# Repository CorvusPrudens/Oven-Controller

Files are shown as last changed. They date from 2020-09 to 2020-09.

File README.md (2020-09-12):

# Oven-Controller
 Hardware, firmware, and support software for an ATMEGA 328-P based reflow oven controller.

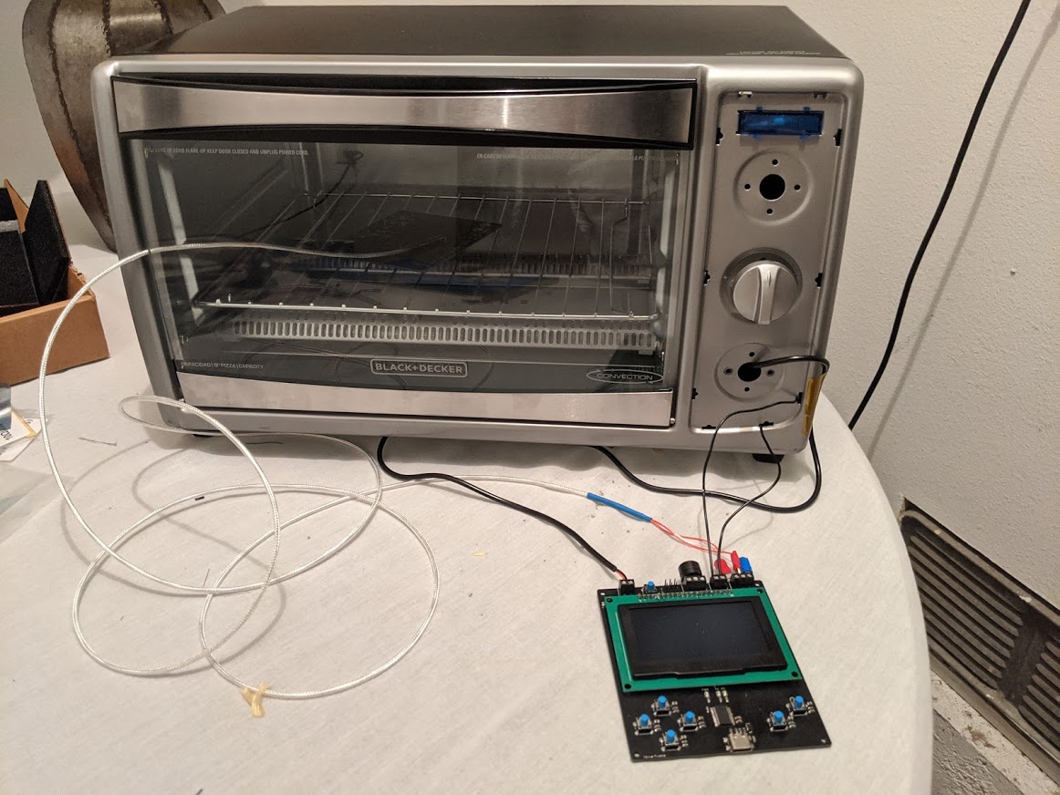
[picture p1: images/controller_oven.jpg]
Oven Controller


## Hardware
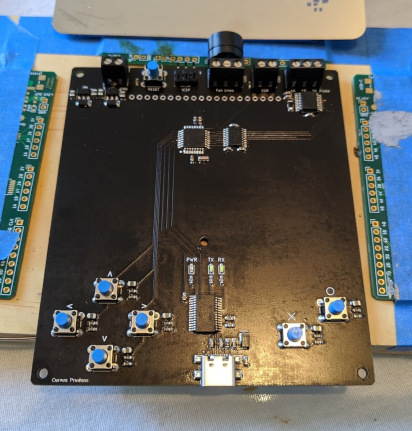
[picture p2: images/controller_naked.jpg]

 The board is controlled by an ATMEGA328-P microcontroller running at 20 MHz. USB communication and flashing is handled with an FT232R USB to UART IC. The board uses a USB-C connector because every modern device should.

 The controller includes a MAX31865 PTD temperature sensor IC with headers for a three-wire PTD probe, a solid state relay, and two additional gpio. The board also include a 7-12 volt power input header and a standard Arduino ICSP header for bootloader flashing.

 The most prominent feature is, of course, the 128x64 pixel OLED display. The on-screen UI is navigated with the 6 pushbuttons arranged in a gamepad-like fashion.

 The board was designed in kiCad, but can be easily ported to Eagle.
<br /><br />
## Firmware
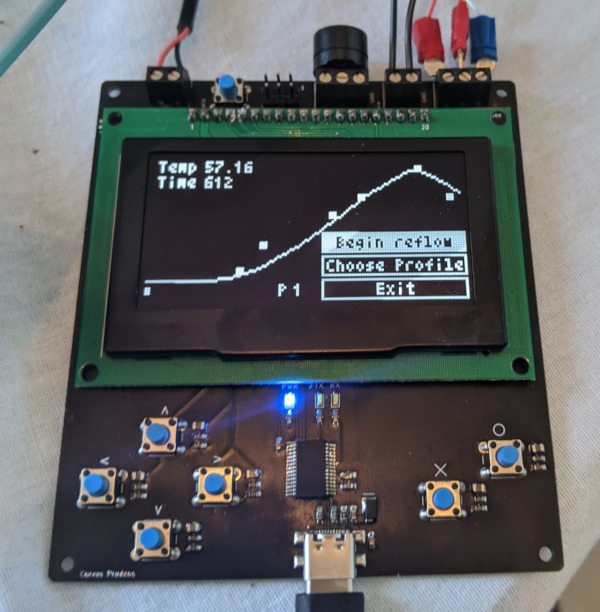
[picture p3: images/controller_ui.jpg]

 The firmware provides an intuitive, menu-based UI for the user. Without any programming or reflashing, the user can define up to eight temperature profiles that persist even after power cycling. These profiles can then be called up to control a modified toaster oven via a solid state relay.

 The firmware provides out of the box support for a piezo buzzer on the available gpio terminal, which provides feedback for UI navigation and an open-door notification.
<br /><br /><br /><br /><br /><br /><br /><br /><br /><br />
## Software
 I have also written a few support programs with Processing and Python. They perform various functions, including generating timer settings for different clock frequencies, generating playable note sequences given a semi-intuitive note table entry, generating bitmaps from images (ideally monochromatic or dichromatic images), and a program that allows a connected computer to log and display the live temperature profile as recorded by the controller.

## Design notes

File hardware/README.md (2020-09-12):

# Hardware

<!-- ![kiCad Design](../images/controller_design.png) -->
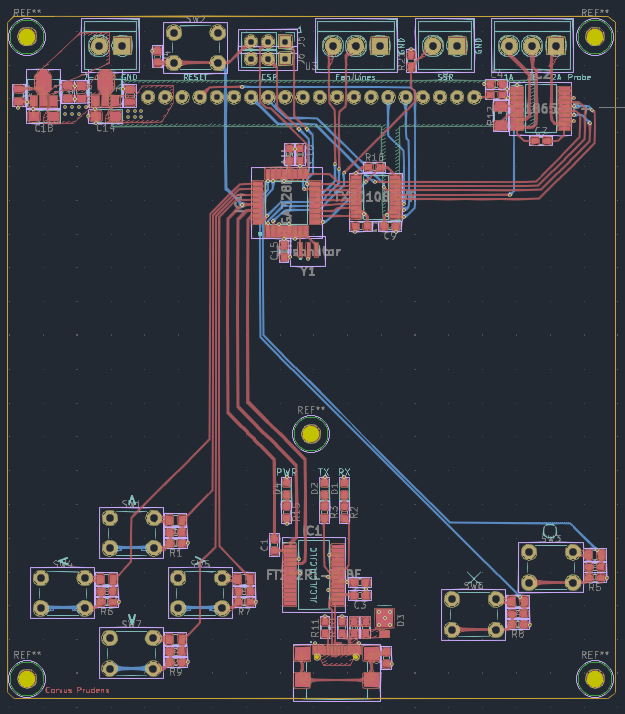
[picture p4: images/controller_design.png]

 This board combines several convenient features together to make an easy to use and highly capable reflow (toaster) oven controller. At the heart of the design is an ATMEGA328-P, with a few support features similar to what you might find on an Arduino board. This allows easy integration with the large Arduino ecosystem and convenient communication and flashing via USB (after flashing a bootloader via the ICSP header). To maximize performance, the 328-P is run at 5 volts -- supplied by either the USB Vbus or the included 7-12 volts LDO regulator. This allows the microcontroller to run at its highest rated frequency, 20 MHz, which is just enough to run all the UI screens at 30 frames per second.

 While the microcontroller can accept 5 volts, the two SPI connected modules -- the MAX31865 PTD probe sensor IC and the OLED display -- need 3.3 volts. Their power is supplied through another LDO, and the communication is routed through a very convenient level shifter, the TXB0108.

 The board itself is a 4 layer design. Of course, 4 layers is completely overkill for this design and would make no sense for a high-volume product. However, this is _not_ a high-volume product, and the manufacturer I use just so happened to drop their 4 layer prices insanely low. I'd be crazy not to make it 4!

 Finally, I'd like to highlight the use of USB-C. If I ever include USB functionality on a device, I will _always_ choose USB-C if I am able. Not only is it an aesthetically pleasing, reversible, fast, and powerful connection -- it's _dead easy_ to design with assuming you don't need its fancier features like power delivery or USB 3.0 (or the dreadfully named USB 3.1 gen 2!). All that's needed for a basic implementation is two resistors and a convenient USB 2.0 rated connector like the one I've used on this board. Give it a try!

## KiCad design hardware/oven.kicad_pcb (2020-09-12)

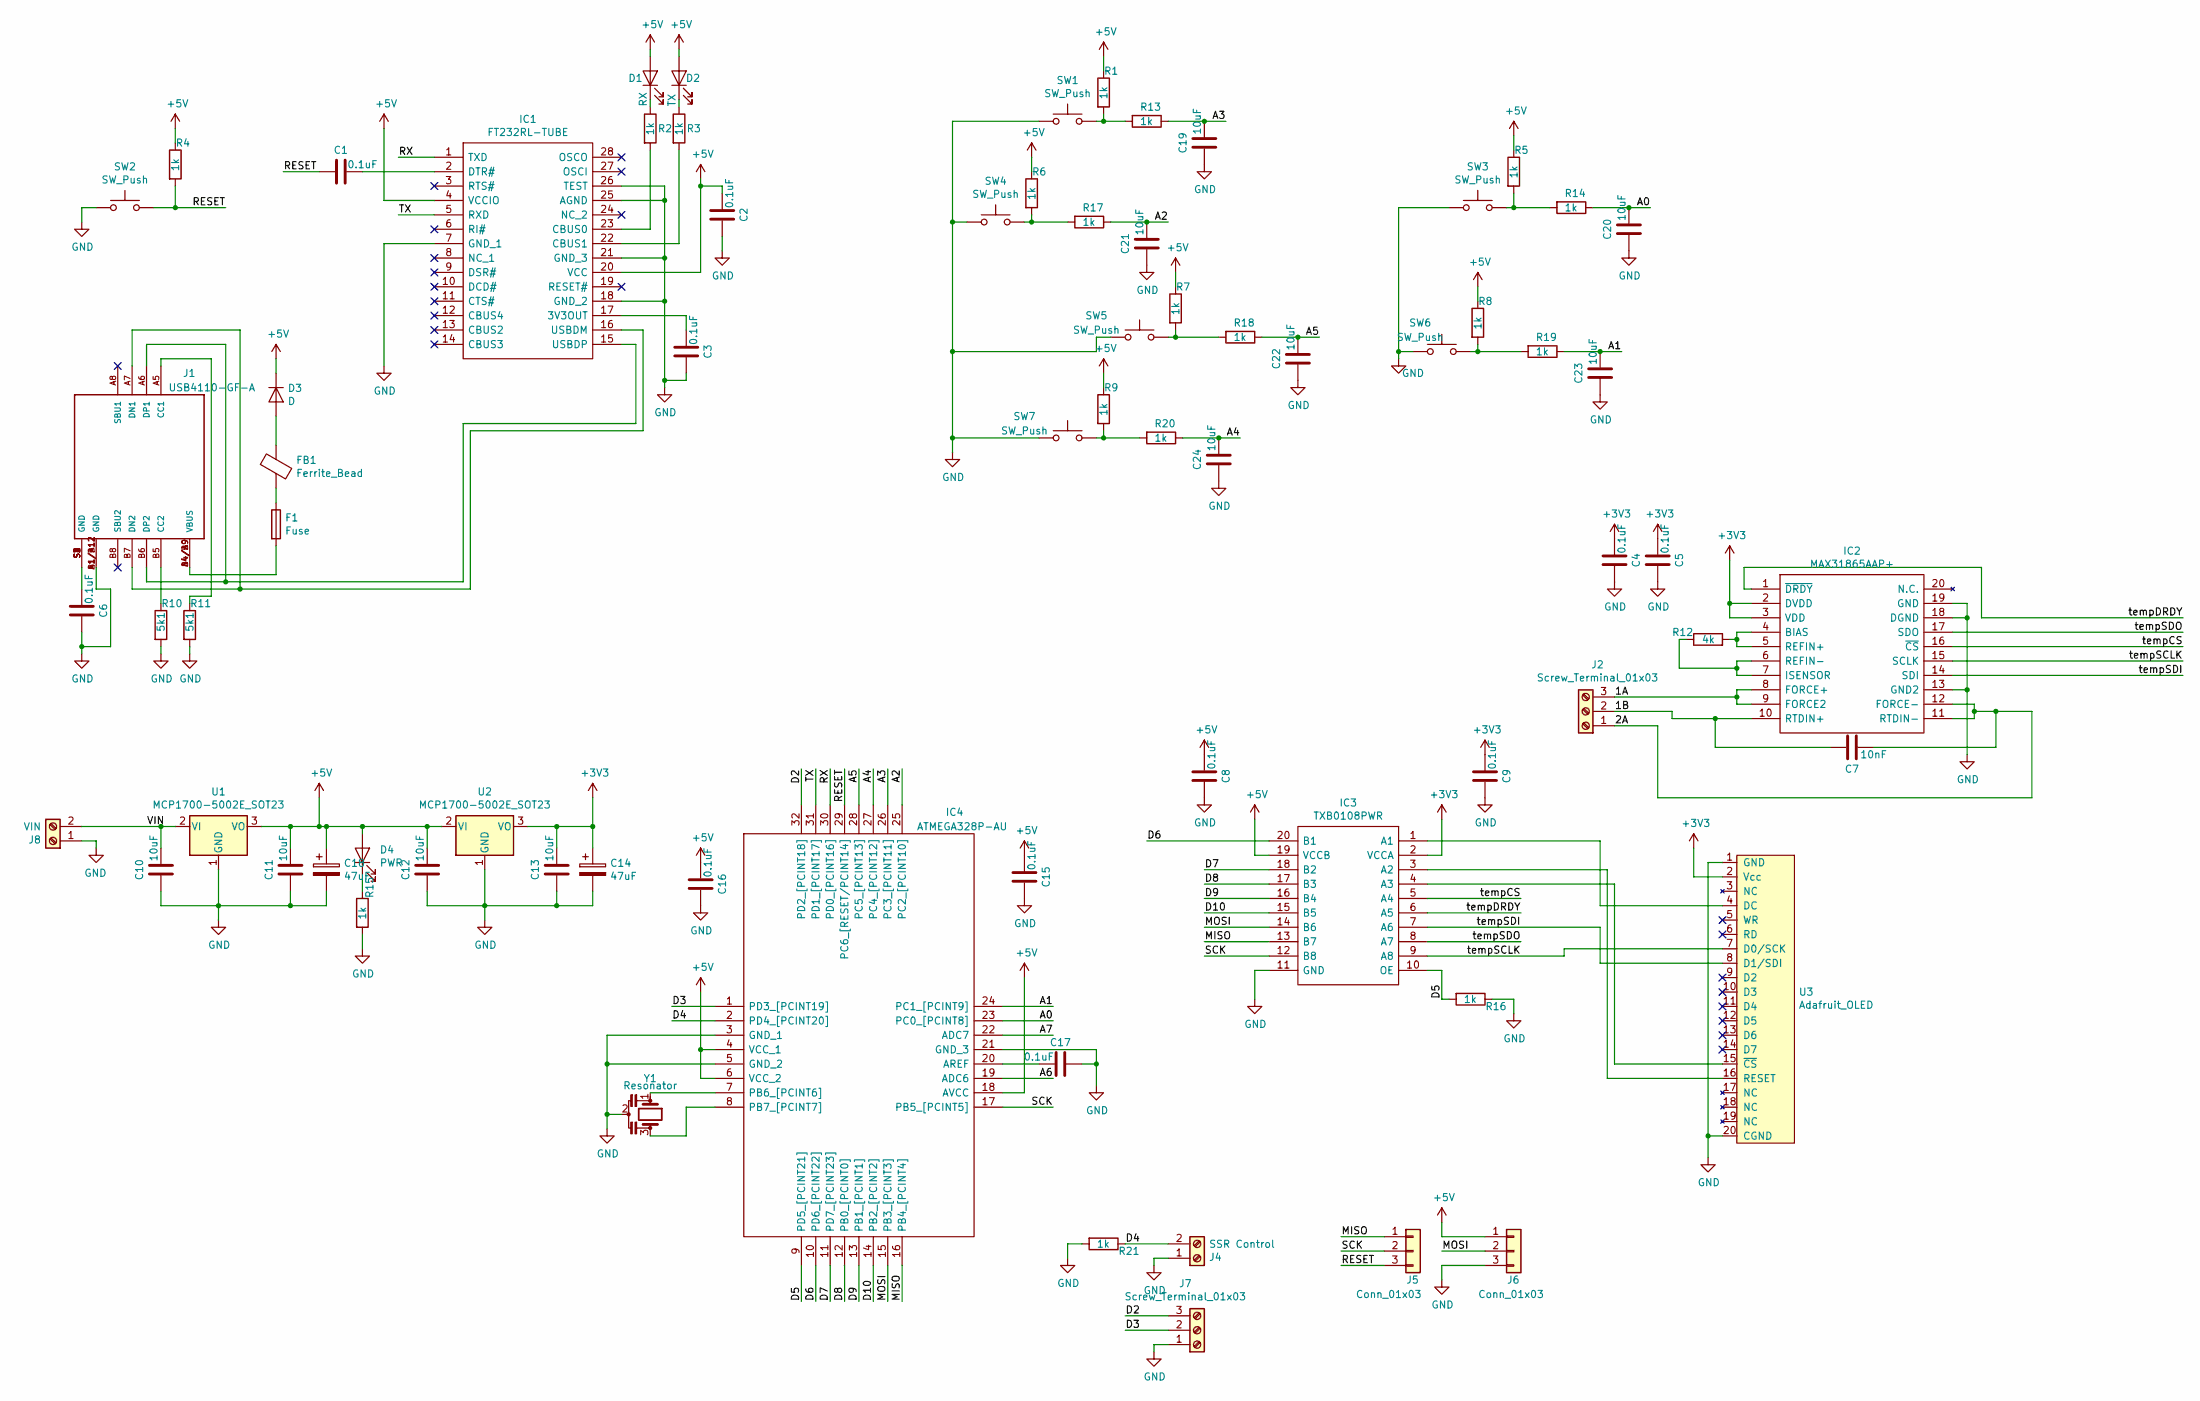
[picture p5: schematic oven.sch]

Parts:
C1, C2, C3, C4, C5, C6, C8, C9, C15, C16, C17: 0.1uF; C_0603_1608Metric_Pad1.05x0.95mm_HandSolder
C7: 10nF; C_0603_1608Metric_Pad1.05x0.95mm_HandSolder
C10, C11, C12, C13, C19, C20, C21, C22, C23, C24: 10uF; C_0805_2012Metric
C14, C18: 47uF; CP_EIA-3216-12_Kemet-S_Pad1.58x1.35mm_HandSolder
D1: RX; LED_0603_1608Metric_Pad1.05x0.95mm_HandSolder
D2: TX; LED_0603_1608Metric_Pad1.05x0.95mm_HandSolder
D3: D; DO-220AA
D4: PWR; LED_0603_1608Metric_Pad1.05x0.95mm_HandSolder
F1: Fuse; Fuse_0603_1608Metric_Pad1.05x0.95mm_HandSolder
FB1: Ferrite_Bead; L_0603_1608Metric_Pad1.05x0.95mm_HandSolder
IC1: FT232RL-TUBE; SOP65P780X200-28N; Mouser Part Number 895-FT232RL-TUBE
IC2: MAX31865AAP+; SOP65P778X199-20N; Mouser Part Number 700-MAX31865AAP+
IC3: TXB0108PWR; SOP65P640X120-20N; Mouser Part Number 595-TXB0108PWR
IC4: ATMEGA328P-AU; QFP80P900X900X120-32N; Mouser Part Number 556-ATMEGA328P-AU
J1: USB4110-GF-A; GCT_USB4110-GF-A
J2, J7: Screw_Terminal_01x03; TerminalBlock_4Ucon_1x03_P3.50mm_Horizontal
J4: SSR Control; TerminalBlock_4Ucon_1x02_P3.50mm_Horizontal
J5, J6: Conn_01x03; PinHeader_1x03_P2.54mm_Vertical
J8: VIN; TerminalBlock_4Ucon_1x02_P3.50mm_Horizontal
R1, R2, R3, R4, R5, R6, R7, R8, R9, R13, R14, R15, R16, R17, R18, R19, R20, R21: 1k; R_0603_1608Metric_Pad1.05x0.95mm_HandSolder
R10, R11: 5k1; R_0603_1608Metric_Pad1.05x0.95mm_HandSolder
R12: 4k; R_0603_1608Metric_Pad1.05x0.95mm_HandSolder
SW1, SW2, SW3, SW4, SW5, SW6, SW7: SW_Push; SW_PUSH_6mm_H4.3mm
U1, U2: MCP1700-5002E_SOT23; SOT-89-3
U3: Adafruit_OLED
Y1: Resonator; CSTNE16M0V530000R0

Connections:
+3V3: C4.2, C5.2, C9.2, C13.1, C14.1, IC2.2 (DVDD), IC2.3 (VDD), IC3.2 (VCCA), U2.3 (VO), U3.2 (Vcc)
+5V: C2.2, C8.2, C11.1, C12.1, C15.2, C16.2, C18.1, D1.2 (A), D2.2 (A), D3.1 (K), D4.2 (A), IC1.4 (VCCIO), IC1.20 (VCC), IC3.19 (VCCB), IC4.4 (VCC_1), IC4.6 (VCC_2), IC4.18 (AVCC), J6.1, R1.1, R4.1, R5.1, R6.1, R7.1, R8.1, R9.1, U1.3 (VO), U2.2 (VI)
/1A: IC2.8 (FORCE+), IC2.9 (FORCE2), J2.3
/1B: C7.1, IC2.10 (RTDIN+), J2.2
/2A: C7.2, IC2.11 (RTDIN-), IC2.12 (FORCE-), J2.1
/A0: C20.1, IC4.23 (PC0_[PCINT8]), R14.1
/A1: C23.1, IC4.24 (PC1_[PCINT9]), R19.1
/A2: C21.1, IC4.25 (PC2_[PCINT10]), R17.1
/A3: C19.1, IC4.26 (PC3_[PCINT11]), R13.1
/A4: C24.1, IC4.27 (PC4_[PCINT12]), R20.1
/A5: C22.1, IC4.28 (PC5_[PCINT13]), R18.1
/A6: IC4.19 (ADC6)
/A7: IC4.22 (ADC7)
/D2: IC4.32 (PD2_[PCINT18]), J7.3
/D3: IC4.1 (PD3_[PCINT19]), J7.2
/D4: IC4.2 (PD4_[PCINT20]), J4.2, R21.1
/D5: IC3.10 (OE), IC4.9 (PD5_[PCINT21]), R16.2
/D6: IC3.20 (B1), IC4.10 (PD6_[PCINT22])
/D7: IC3.18 (B2), IC4.11 (PD7_[PCINT23])
/D8: IC3.17 (B3), IC4.12 (PB0_[PCINT0])
/D9: IC3.16 (B4), IC4.13 (PB1_[PCINT1])
/D10: IC3.15 (B5), IC4.14 (PB2_[PCINT2])
/MISO: IC3.13 (B7), IC4.16 (PB4_[PCINT4]), J5.1
/MOSI: IC3.14 (B6), IC4.15 (PB3_[PCINT3]), J6.2
/RESET: C1.2, IC4.29 (PC6_[RESET/PCINT14]), J5.3, R4.2, SW2.2
/RX: IC1.1 (TXD), IC4.30 (PD0_[PCINT16])
/SCK: IC3.12 (B8), IC4.17 (PB5_[PCINT5]), J5.2
/TX: IC1.5 (RXD), IC4.31 (PD1_[PCINT17])
/VIN: C10.1, J8.2, U1.2 (VI)
/tempCS: IC2.16 (~CS), IC3.5 (A4)
/tempDRDY: IC2.1 (~DRDY), IC3.6 (A5)
/tempSCLK: IC2.15 (SCLK), IC3.9 (A8), U3.7 (D0/SCK)
/tempSDI: IC2.14 (SDI), IC3.7 (A6), U3.8 (D1/SDI)
/tempSDO: IC2.17 (SDO), IC3.8 (A7)
GND: C2.1, C3.1, C4.1, C5.1, C6.1, C8.1, C9.1, C10.2, C11.2, C12.2, C13.2, C14.2, C15.1, C16.1, C17.1, C18.2, C19.2, C20.2, C21.2, C22.2, C23.2, C24.2, IC1.7 (GND_1), IC1.18 (GND_2), IC1.21 (GND_3), IC1.25 (AGND), IC1.26 (TEST), IC2.13 (GND2), IC2.18 (DGND), IC2.19 (GND), IC3.11 (GND), IC4.3 (GND_1), IC4.5 (GND_2), IC4.21 (GND_3), J1.A1/B12 (GND), J1.B1/A12 (GND), J4.1, J6.3, J7.1, J8.1, R10.2, R11.2, R15.2, R16.1, R21.2, SW1.1, SW2.1, SW3.1, SW4.1, SW5.1, SW6.1, SW7.1, U1.1 (GND), U2.1 (GND), U3.1 (GND), U3.20 (CGND), Y1.2
unnamed: C1.1, IC1.2 (DTR#)
unnamed: C3.2, IC1.17 (3V3OUT)
unnamed: C6.2, J1.S1 (GND), J1.S2 (GND), J1.S3 (GND), J1.S4 (GND)
unnamed: C17.2, IC4.20 (AREF)
unnamed: D1.1 (K), R2.1
unnamed: D2.1 (K), R3.1
unnamed: D3.2 (A), FB1.1
unnamed: D4.1 (K), R15.1
unnamed: F1.1, FB1.2
unnamed: F1.2, J1.A4/B9 (VBUS), J1.B4/A9 (VBUS)
unnamed: IC1.15 (USBDP), J1.A6 (DP1), J1.B6 (DP2)
unnamed: IC1.16 (USBDM), J1.A7 (DN1), J1.B7 (DN2)
unnamed: IC1.22 (CBUS1), R3.2
unnamed: IC1.23 (CBUS0), R2.2
unnamed: IC2.4 (BIAS), IC2.5 (REFIN+), R12.2
unnamed: IC2.6 (REFIN-), IC2.7 (ISENSOR), R12.1
unnamed: IC3.1 (A1), U3.4 (DC)
unnamed: IC3.3 (A2), U3.16 (RESET)
unnamed: IC3.4 (A3), U3.15 (~CS)
unnamed: IC4.7 (PB6_[PCINT6]), Y1.1
unnamed: IC4.8 (PB7_[PCINT7]), Y1.3
unnamed: J1.A5 (CC1), R11.1
unnamed: J1.B5 (CC2), R10.1
unnamed: R1.2, R13.2, SW1.2
unnamed: R5.2, R14.2, SW3.2
unnamed: R6.2, R17.2, SW4.2
unnamed: R7.2, R18.2, SW5.2
unnamed: R8.2, R19.2, SW6.2
unnamed: R9.2, R20.2, SW7.2

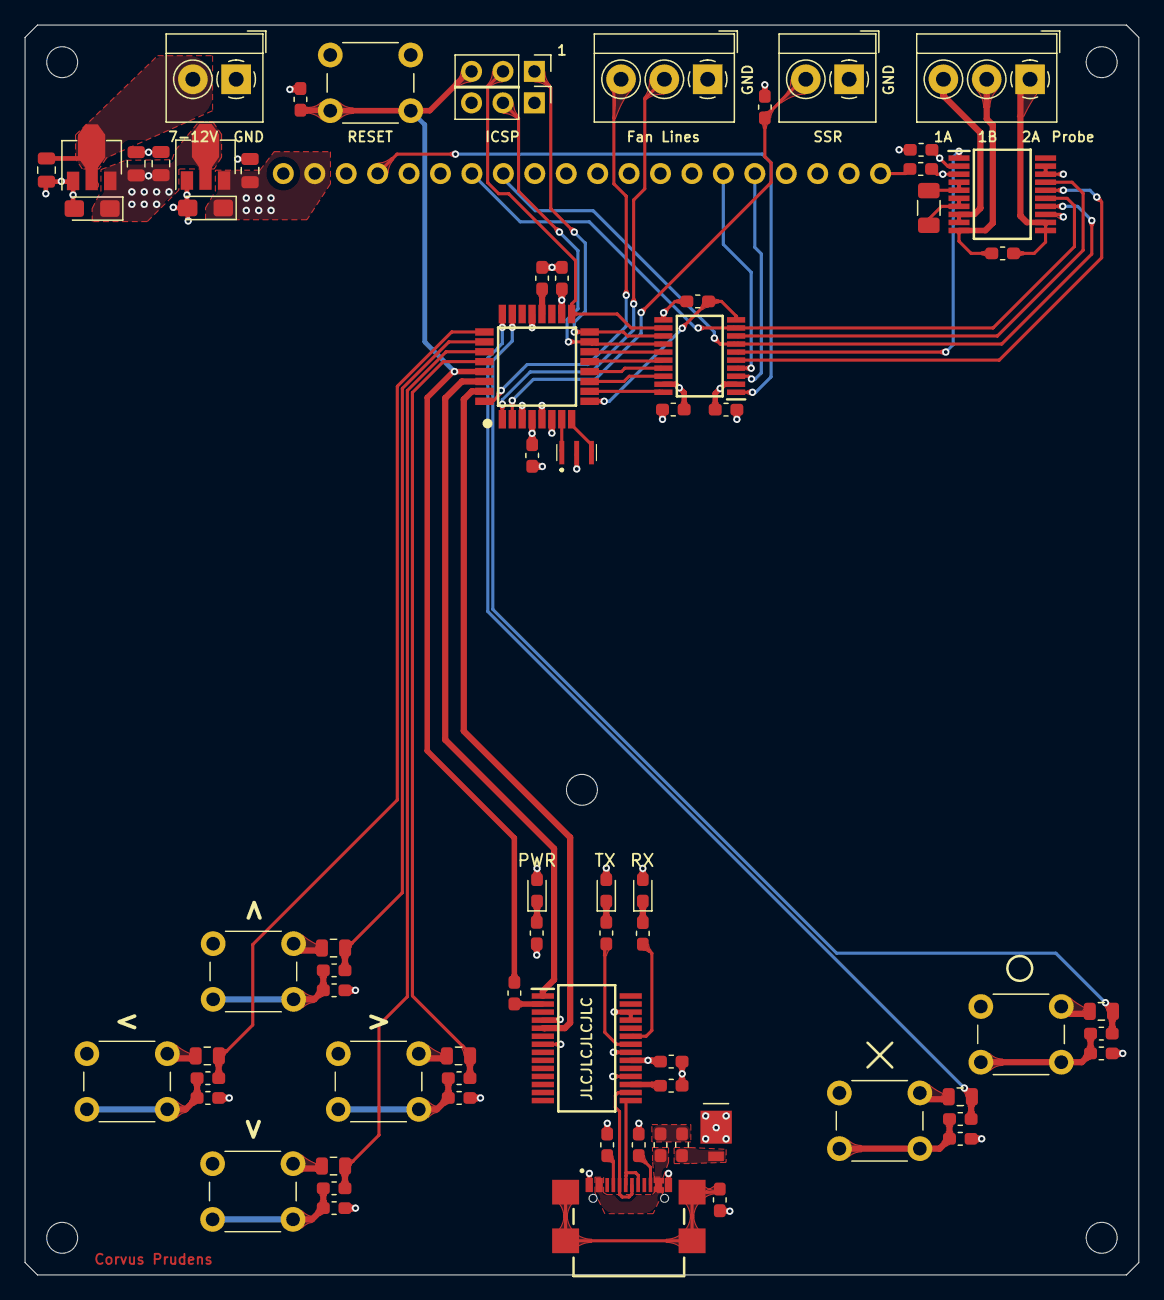
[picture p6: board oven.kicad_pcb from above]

Board: 4 copper layers, 90.0 x 101.0 mm, 73 parts (0 on the bottom side), 62 nets.

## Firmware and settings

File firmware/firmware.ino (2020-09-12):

byte clockState = 0;
byte frameTick = 0;
byte secondTick = 0;
byte minuteTick = 0;

#define JUST_SECOND 1
#define JUST_MINUTE 2

#include <SPI.h>

#include "Display.h"
#include "utility.h"
#include "pt100.h"
#include "audio.h"
#include "gfx.h"
#include "Buttons.h"
#include "Menus.h"

#define OLED_CS 8
#define OLED_RESET 7
#define OLED_DC 6

long delta;

void tick() {
  frameTick++;
  clockState = 0;
  if (frameTick == 30) {
    clockState |= JUST_SECOND;
    frameTick = 0;
    secondTick++;
  }
  if (secondTick == 60) {
    clockState |= JUST_MINUTE;
    secondTick = 0;
    minuteTick++;
  }
}

volatile byte newFrame = 0;

void setup() {
  
  // TXB0108 level shifter enable
  // We'll just leave this high for now
  pinMode(5, OUTPUT);
  digitalWrite(5, HIGH);

  // MAX chip select
  pinMode(9, OUTPUT);
  digitalWrite(9, HIGH);

  // SSR control
  pinMode(4, OUTPUT);
  digitalWrite(4, LOW);

  display_begin(OLED_DC, OLED_RESET, OLED_CS);
  clearDisplay();
  setFont(tomFont);

  beginMAX();

  setTimer1();

  pinMode(A0, INPUT_PULLUP);
  pinMode(A1, INPUT_PULLUP);
  pinMode(A2, INPUT_PULLUP);
  pinMode(A3, INPUT_PULLUP);
  pinMode(A4, INPUT_PULLUP);
  pinMode(A5, INPUT_PULLUP);

  Serial.begin(115200);
  // Buzzer pin
  pinMode(2, OUTPUT);
  setTimer2();
  setTimer0();
  // beginSequence(mariovict);
  // disableAudio();

  //  // DEBUG MODE
  //  for (byte i = 0; i < PROFILES_HEADER; i++){
  //    EEPROM.update(i, 0);
  //  }
}

ISR(TIMER1_COMPA_vect) { //timer1 interrupt @30Hz
  newFrame = 1;
}

byte second = 0;
float reading = 150.0;
byte toggley = 0;
byte skytick = 0;
//long ti = micros();

void loop() {
  if (newFrame == 1) {

    long ti = micros();
    tick();
    clearDisplay();
    //    printVal(minuteTick, secondTick, secondTick);
    //    printVal(secondTick, secondTick + 15, secondTick);
    //    delta = micros();
    newFrame = 0;
    anim += 3;
    serialC = 255;
    //    if (Serial.available() > 0) {
    //      serialC = Serial.read();
    //    }
    getButtons(serialC);
    getButtonTimes();

    menuSys();
    display();
    
    //sendData(buttons, buttonTimes);
  }
}

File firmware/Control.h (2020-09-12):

#define THERMAL_INERTIA 22

const float defaultMaxChange[] PROGMEM = {
  0.8,
  0.8,
  0.8,
  0.7,
  0.6
};

const float defaultMinPWM[] PROGMEM = {
  0.4,
  0.4,
  0.4,
  0.55,
  0.65
};

const uint16_t defaultOvershoot[] PROGMEM = {
  25,
  25
}; 


// The SSR pin is D4
void elementsOn() {
  Serial.write(30);
  PORTD |= 0b00010000;
}

void elementsOff() {
  // debug
  Serial.write(0);
  PORTD &= 0b11101111;
}

void elementsPWM(float duty) {
  float translate = duty * 30;
  //debug mode
  Serial.write((byte)round(translate));
  //printVal(translate, 110, 50);
  if (frameTick < translate) {
    elementsOn();
    //debug
    //Serial.write(1);
  } else {
    elementsOff();
    //Serial.write(0);
  }
}

// The temperatures will be implicit:
// 0-50, 50-100, 100-150, 150-200, 200-250

// Default values that we'll use for now
float maxChange[5] = {
  0.8,
  0.8,
  0.8,
  0.7,
  0.6
};
float minPWM[5] = {
  0.4,
  0.4,
  0.4,
  0.55,
  0.65
};

// 100, 200
uint16_t overshoot[2];

byte openDoor = 0;

// I should really just store these values as uint16_t and cut the number of available profiles in half!!!!!!
// The x and y position on screen should be mapped from the maximum x and y positions (maybe include these in profile array?)

float tempAt(uint16_t profile, uint16_t tim) {
  // need to make exception for when a profile isn't saved to eeprom
  // oh yeah this caused an error and low key scared me
  float temp = 0;
  int16_t numPoints;
  int16_t tempval0;
  int16_t tempval1;
  int16_t tempval2;
  int16_t tempval3;
  EEPROM.get(profile, numPoints);

  EEPROM.get(profile + 6 + (numPoints - 1) * 4, tempval0);

  if (tim >= tempval0) {
    EEPROM.get(profile + 6 + (numPoints - 1) * 4 + 2, tempval0);
    return tempval0;
  }
//  else {
//    // this is a total hack, but should work for now
//    EEPROM.get(profile + 6 + (numPoints - 2) * 4, tempval0);
//    if (tim > tempval0){
//      return 50;
//    }
//  }
  
  uint16_t targindex = 0;
  // There seems to be a bug when we search between the last two points
  for (byte i = 1; i < numPoints; i++) {
    EEPROM.get(profile + 6 + i * 4, tempval0);
    if (tim < tempval0) {
      targindex = (i - 1) * 4 + 6; // this is a little confusing, but necessary with our limitations.
      // the target index is the previous point, so i - 1. The times four is because the x and y values are stored
      // in a 1d array and they are both 2 bes. The plus 6 is because the beginning of the array stores how many points follow and stuff.
      break;
    } else if (tim == tempval0) {
      EEPROM.get(profile + 6 + i * 4 + 2, tempval0);
      return (tempval0);
    }
  }

  //printVal((targindex - 6)/4 - 1, 64, 50);
  
  EEPROM.get(profile + targindex + 6, tempval0);
  EEPROM.get(profile + targindex + 2, tempval1);
  EEPROM.get(profile + targindex + 4, tempval2);
  EEPROM.get(profile + targindex, tempval3);
  float segAng = atan2((tempval0 - tempval1),     //y2 - y1
                       (tempval2 - tempval3));      //x2 - x1

  float xdiff = tim - tempval3;
  temp = float(tempval1) + tan(segAng) * xdiff;

  return temp;
}

// Rate of change in degrees C per second
float changeAt(uint16_t profile, float tim, byte lookahead) {
  float change = 0;

  for (byte i = 0; i < lookahead; i++) {
    change += tempAt(profile, i + tim + 1) - tempAt(profile, i + tim);
  }

  return change / (float)lookahead;
}

float changeTo(float tempNow, uint16_t profile, float tim, byte lookahead){
  float avgtemp = 0;
  float change = 0;

  // getting the average temperature of the next <lookahead> number of seconds
  for (byte i = 0; i < lookahead; i++){
    avgtemp += tempAt(profile, tim + 1 + i + THERMAL_INERTIA);
  }
  avgtemp /= (float)lookahead;
  float avgtim = (20 + lookahead + 1)/2.0;

//  printFloat(avgtemp, 110, 32);
//  printFloat(tempAt(profile, tim + 1 + THERMAL_INERTIA), 110, 39);
  //printFloat (avgtim, 110, 39);
  return (avgtemp - tempNow)/avgtim;
  // basically, just calculate the change necessary between the current temperature and the
  // temperature we're supposed to be at, and then look up what PWM that chagne corresponds to
  // at our current temperature
}

// Note, each index rerpresesnts a time change of 2 seconds!
float changeAtMeasurement(uint16_t* tempbuff, uint16_t tim, byte lookbehind) {
  float change = 0;

  for (byte i = 0; i < lookbehind; i++) {
    change += float(tempbuff[tim - i] - tempbuff[tim - i - 1])/2;
  }
  return change / (float)lookbehind;
}

float lookbehindBuffer[5];

float changeAtMeasurement(float* tempbuff, float temp){
  static byte depth = 0;
  float change = 0.5;
  for (byte i = 3; i < 255; i--){
    tempbuff[i + 1] = tempbuff[i];
  }
  tempbuff[0] = temp;

  if (depth < 5){
    depth++;
  } else{
    change = 0;
    for (byte i = 1; i < 5; i++){
      // these will be acquired every second instead of every two
      change += (tempbuff[i - 1] - tempbuff[i]);
    }
    change /= 4.0;
  }
  
  return change;
}

// MAX RATE OF CHANGE TO TARGET: Maximum oven capabilities
// MIN RATE OF CHANGE TO TARGET: 0.5 C/s



//    // The temperatures will be implicit:
//    // 0-50, 50-100, 100-150, 150-200, 200-250
//    float maxChange[5];
//    float minPWM[5];
//
//    // 100, 200
//    float overshoot[2];

//    boolean openDoor = false;
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
